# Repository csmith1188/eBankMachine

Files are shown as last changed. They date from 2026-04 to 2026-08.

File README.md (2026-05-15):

# eBanks Machine

ESP32-powered DigiPog / Pog kiosk with keypad control, NFC card support, Formbar transfers, servo-driven dispensing, deposit sensing, and a web debug / OTA page.

---

## 1. What you need

### Software

- Arduino IDE 2.x
- ESP32 board support package
- USB serial driver for your ESP32 board
- This project folder with `eBankMachine.ino` and the `.cpp/.h` files in the same sketch folder

### Arduino libraries

Install these from the Arduino Library Manager unless you already have them:

- `ArduinoJson`
- `LiquidCrystal_I2C`
- `Keypad`
- `ESP32Servo`
- `Adafruit PN532`
- `Crypto`

The ESP32 core provides these automatically:

- `WiFi`
- `WebServer`
- `ESPmDNS`
- `Update`
- `HTTPClient`
- `WiFiClientSecure`
- `Wire`

---

## 2. USB driver setup

Your computer needs the correct USB-to-serial driver before the ESP32 appears as a port.

### How to tell which driver you need

Look at the small USB chip on the ESP32 board, near the USB port.

Common chips:

| Chip on board | Driver to install |
|---|---|
| CH340 / CH341 | CH340 driver |
| CP2102 / CP210x | Silicon Labs CP210x driver | `The one I used `
| FT232 / FTDI | FTDI VCP driver |
| Native USB ESP32-S2 / S3 / C3 | Usually no extra driver needed on modern Windows/macOS/Linux |

Most cheap ESP32 DevKit boards use either **CH340** or **CP2102**.

### Windows

1. Plug in the ESP32 with a data USB cable.
2. Open **Device Manager**.
3. Check **Ports (COM & LPT)**.
4. If you see something like `USB-SERIAL CH340`, `CP210x USB to UART Bridge`, or `USB Serial Device`, the driver is working.
5. If it shows up under **Other devices** or has a warning icon, install the matching driver.
6. Unplug and replug the ESP32 after installing the driver.
7. In Arduino IDE, go to **Tools > Port** and select the new COM port.

### macOS

1. Plug in the ESP32 with a data USB cable.
2. In Arduino IDE, check **Tools > Port**.
3. Look for a port like:
   - `/dev/cu.usbserial-*`
   - `/dev/cu.SLAB_USBtoUART`
   - `/dev/cu.wchusbserial*`
4. If no port appears, install the CH340 or CP210x driver depending on the board.
5. Reboot if macOS still does not show the port.

### Linux / Chromebook Linux container

1. Plug in the ESP32.
2. Run:

```bash
ls /dev/ttyUSB* /dev/ttyACM*
```

3. Common ports are:
   - `/dev/ttyUSB0`
   - `/dev/ttyACM0`

4. If the port exists but Arduino cannot use it, add your user to the serial group:

```bash
sudo usermod -aG dialout $USER
```

5. Log out and back in.

---

## 3. USB cable warning

A lot of USB cables are charge-only. They power the ESP32 but do not carry data.

If the ESP32 lights up but no port appears:

- Try a different USB cable.
- Try a different USB port.
- Avoid USB hubs while troubleshooting.
- Use a cable that you know can transfer files, not just charge.

---

## 4. Arduino IDE board settings

In Arduino IDE:

1. Install ESP32 board support:
   - Open **Boards Manager**.
   - Search `esp32`.
   - Install **esp32 by Espressif Systems**.
2. Select a board:
   - Usually **ESP32 Dev Module** works.
3. Select the port:
   - **Tools > Port > COMx** on Windows
   - **Tools > Port > /dev/cu...** on macOS
   - **Tools > Port > /dev/ttyUSB0** or `/dev/ttyACM0` on Linux
4. Good default upload settings:
   - Upload Speed: `115200` or `921600`
   - CPU Frequency: `240MHz`
   - Flash Mode: `DIO`
   - Partition Scheme: `Default 4MB with spiffs` or normal default

If upload fails at `Connecting...`, hold the ESP32 **BOOT** button until the upload starts, then release it.

---

## 5. First upload

1. Open `eBankMachine.ino` in Arduino IDE.
2. Make sure all project files are in the same sketch folder.
3. Click **Verify**.
4. Fix any missing library errors.
5. Click **Upload**.
6. Open Serial Monitor at `115200 baud`.

After booting, the LCD should show the startup / welcome screens.

---

## 6. Finding the ESP32 on the network

The machine connects to Wi-Fi using the values in `config.cpp`.

Before uploading, set:

```cpp
const char* WIFI_SSID = "YOUR_WIFI_NAME";
const char* WIFI_PASS = "YOUR_WIFI_PASSWORD";
```

### Option A: use the keypad

Press **B three times** on the keypad. The LCD should show the ESP32 IP address if Wi-Fi is connected.

Then open:

```text
http://ESP_IP_ADDRESS/
http://ESP_IP_ADDRESS/debug
```

Example:

```text
http://192.168.1.50/debug
```

### Option B: use Serial Monitor

Open Serial Monitor at `115200 baud` and reset the ESP32.

Look for lines like:

```text
HTTP: http://192.168.x.x/
Debug: http://192.168.x.x/debug
```

### Option C: try mDNS

The project sets an OTA host name. Try:

```text
http://digipog-kiosk.local/
http://digipog-kiosk.local/debug
```

This may not work on every school network or Windows setup. The raw IP address is more reliable.

---

## 7. Web pages

### Main OTA page

```text
http://ESP_IP_ADDRESS/
```

Default login page:

```text
username: admin
password: admin
```

The OTA upload form then asks for the OTA password from `config.cpp`.

### Debug page

```text
http://ESP_IP_ADDRESS/debug
```

The debug page shows:

- current mode
- motion state
- Wi-Fi status
- inventory count
- limit switch status
- live debug log
- testing controls
- servo test buttons
- IR scan tools
- NFC scan tools
- reboot button

Warning: in the current code, `/debug` is not protected by a login. Anyone on the same network who knows the IP can open it.

---

## 8. OTA update flow

After the first USB upload, you can upload newer firmware through the browser.

1. Build/export the compiled binary from Arduino IDE.
2. Open:

```text
http://ESP_IP_ADDRESS/
```

3. Log in.
4. Choose the `.bin` file.
5. Enter the OTA password.
6. Upload.
7. The ESP32 reboots after a successful update.

If OTA fails, go back to USB upload.

---

## 9. Troubleshooting: computer cannot find ESP32

### No port appears at all

Most likely causes:

- charge-only USB cable
- missing CH340 / CP210x driver
- bad USB port
- bad board

Fix:

1. Try another USB cable.
2. Try another USB port.
3. Install the correct USB serial driver.
4. Replug the board.
5. Check Device Manager / Arduino Port menu again.

### Port appears, but upload fails

Try:

- Hold **BOOT** while uploading.
- Press **EN / RESET** once when Arduino says `Connecting...`.
- Lower upload speed to `115200`.
- Close Serial Monitor before uploading.
- Make sure no other program is using the COM port.

### Upload works, but Wi-Fi page does not load

Check:

- Wi-Fi SSID and password in `config.cpp`.
- ESP32 and computer are on the same network.
- School networks may block device-to-device traffic.
- Use the IP from the LCD or Serial Monitor instead of `.local`.

### `.local` address does not work

Use the IP address instead:

```text
http://ESP_IP_ADDRESS/debug
```

mDNS is convenient, but it is not guaranteed on every network.

### ESP32 keeps rebooting

Check:

- power supply is stable
- servo is not pulling too much current from the ESP32
- wiring shorts
- Serial Monitor crash messages
- correct board selected in Arduino IDE

---

## 10. Important security notes

This project contains Wi-Fi credentials, API keys, kiosk account info, and OTA credentials in code.

Before sharing publicly:

- remove real Wi-Fi passwords
- rotate exposed API keys
- remove real kiosk PINs
- move secrets into a separate ignored config file
- protect `/debug`
- change the default web login

Recommended repo setup:

```text
config.example.cpp   safe placeholder config
config.cpp           real private config, ignored by git
.gitignore           includes config.cpp
```

Example `.gitignore` entry:

```gitignore
config.cpp
*.bin
*.elf
*.map
```

---

## 11. Basic mode controls

From the main menu:

| Key | Mode |
|---|---|
| A | DigiPogs to Pogs / withdraw |
| B | Pogs to DigiPogs / deposit |
| C | Student-to-student transfer |
| D | NFC card write |
| B x3 | Show IP address |

Inside most flows:

| Key | Action |
|---|---|
| `#` | confirm / next |
| `*` | cancel / clear / back |

---

## 12. Current known notes

- `/debug` is powerful and currently not protected.
- First upload must be done over USB.
- OTA only works after Wi-Fi connects.
- If the ESP32 cannot be found, fix USB drivers/cable before debugging the code.
- If the network blocks local devices, the web UI may not load even though Wi-Fi connects.

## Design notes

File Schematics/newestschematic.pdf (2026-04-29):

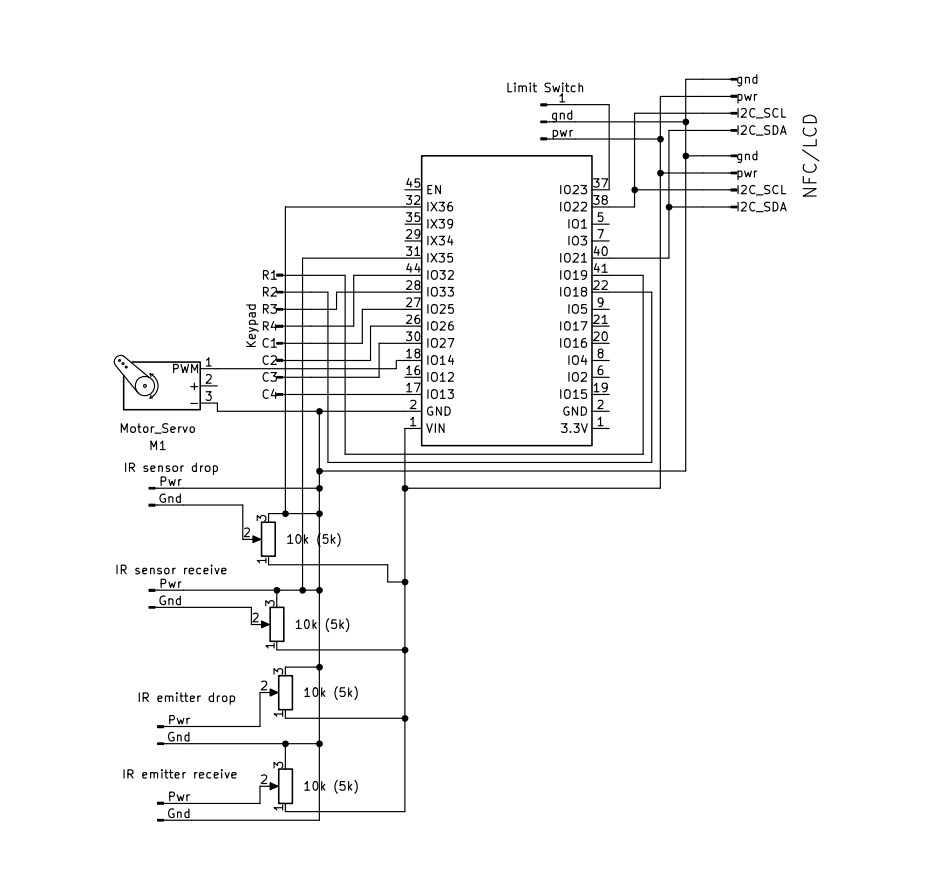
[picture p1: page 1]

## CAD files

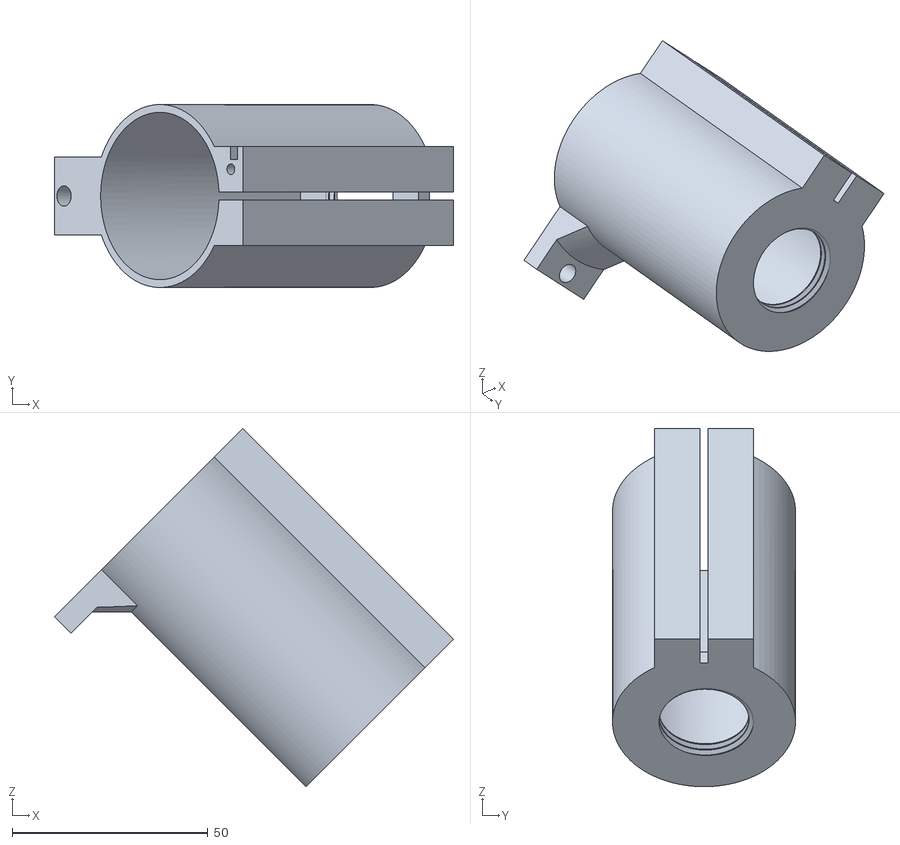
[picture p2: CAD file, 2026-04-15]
atm_stls/Dispensor_PogDispensor v14_Box_1_Body1.stl
102.0 x 46.8 x 91.6

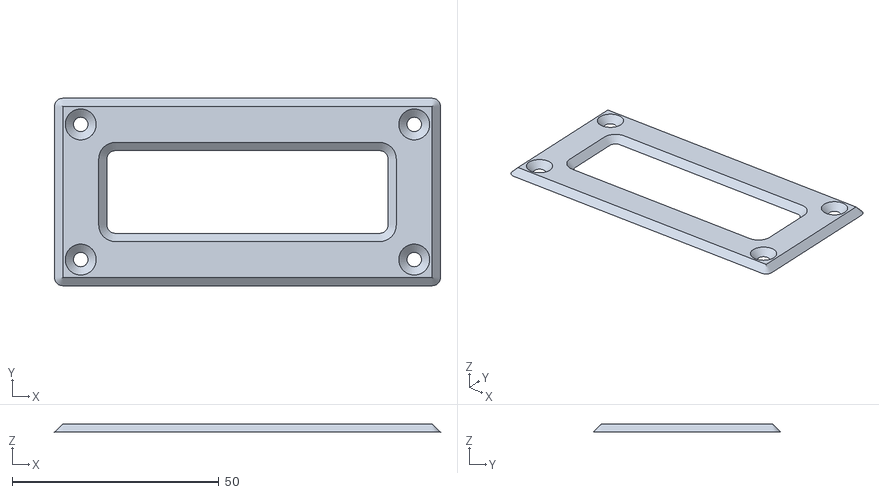
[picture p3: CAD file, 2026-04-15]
atm_stls/Panels_ATM_Panels v2_LCD_1_Body1.stl
93.4 x 45.4 x 2.00

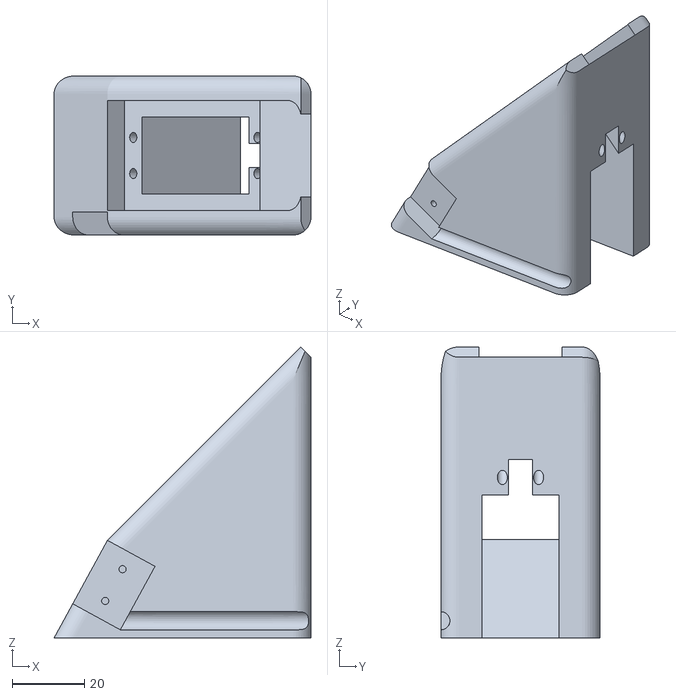
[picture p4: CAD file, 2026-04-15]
atm_stls/Dispensor_PogDispensor v14_Stand_1_Body1.stl
71.1 x 44.0 x 80.5

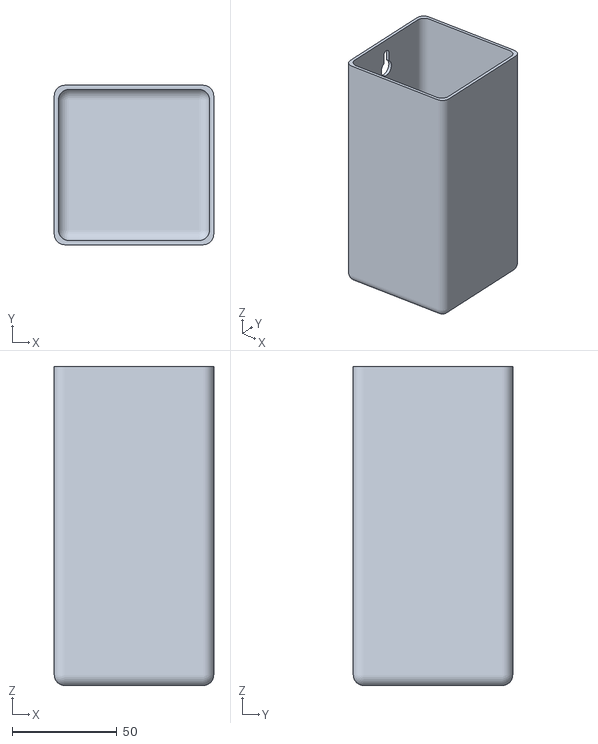
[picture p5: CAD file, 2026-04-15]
atm_stls/ReceiverBox.stl
76.2 x 76.2 x 152.4

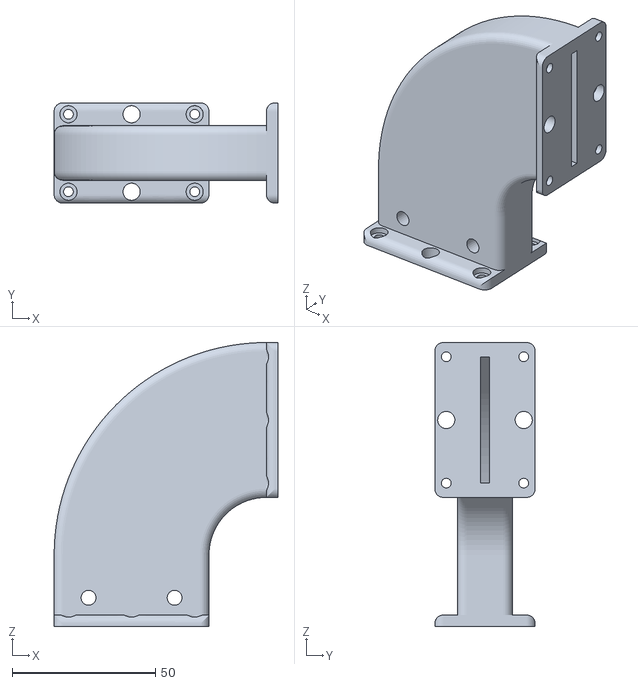
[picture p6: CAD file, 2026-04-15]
atm_stls/Receiver.stl
78.0 x 35.0 x 99.0

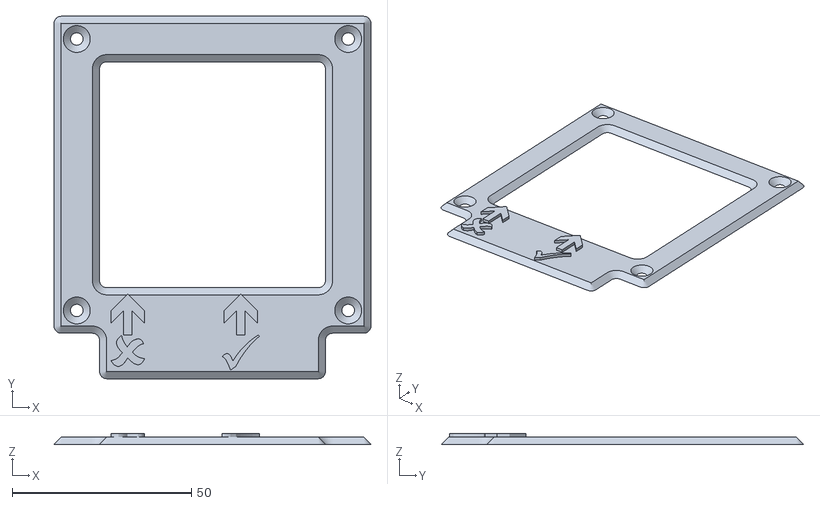
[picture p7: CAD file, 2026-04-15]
atm_stls/Panels_ATM_Panels v2_Keypad_1_Body1.stl
88.4 x 101.1 x 3.00

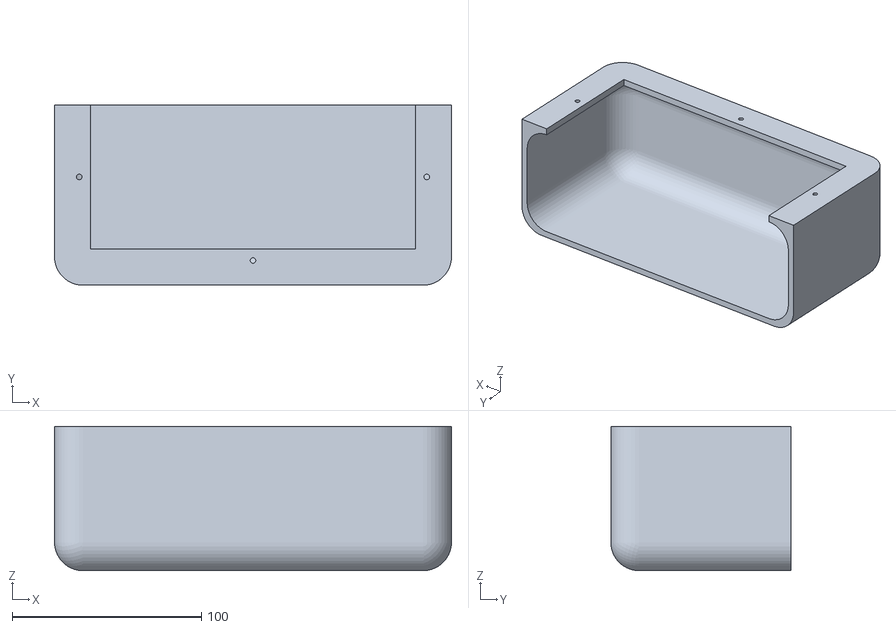
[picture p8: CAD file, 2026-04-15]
atm_stls/DropperBox.stl
209.5 x 95.2 x 76.2

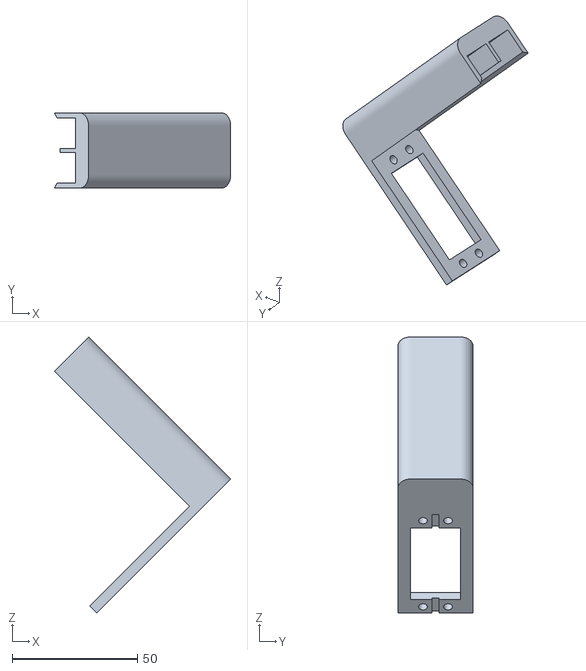
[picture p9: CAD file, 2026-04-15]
atm_stls/Dispensor_PogDispensor v14_Motor_1_Body1.stl
70.3 x 30.0 x 110.2

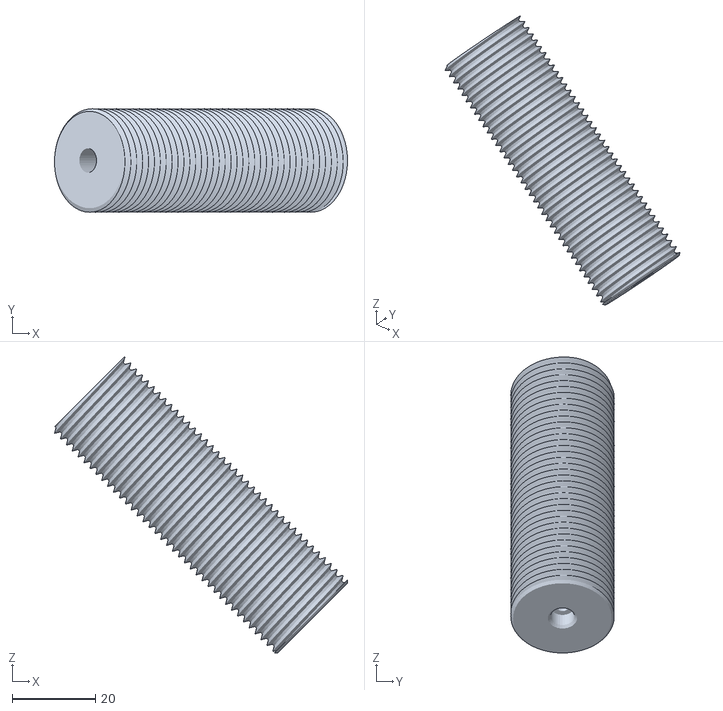
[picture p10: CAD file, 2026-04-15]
atm_stls/Dispensor_PogDispensor v14_Scroo_1_Body1.stl
70.3 x 24.8 x 71.0

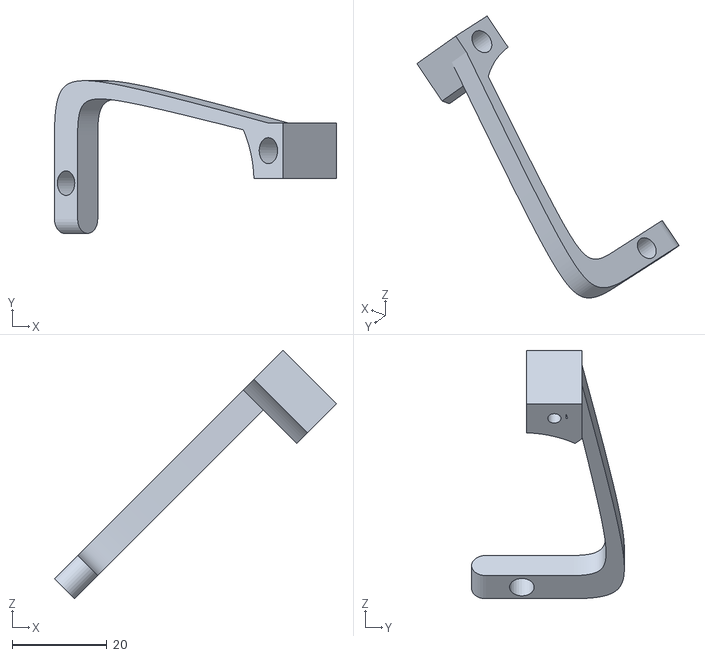
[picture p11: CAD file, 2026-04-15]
atm_stls/Dispensor_PogDispensor v14_IRArm_1_Body1.stl
59.5 x 32.2 x 52.4

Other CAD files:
atm_stls/Dropper.f3d
atm_stls/DropperBox.f3d
atm_stls/Panels.f3d
atm_stls/Receiver.f3d
atm_stls/ReceiverBox.f3d

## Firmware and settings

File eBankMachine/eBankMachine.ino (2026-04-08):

#include "eBankMachine.h"

void setup() {
  Serial.begin(115200);
  delay(200);

  dbgClear();
  dbgPrintf("BOOT\n");

  hardwareInit();

  // WiFi initial connect (15s)
  WiFi.mode(WIFI_STA);
  WiFi.setSleep(false);
  WiFi.begin(WIFI_SSID, WIFI_PASS);

  unsigned long startAttemptTime = millis();
  while (WiFi.status() != WL_CONNECTED && millis() - startAttemptTime < 15000) {
    delay(250);
  }



  if (WiFi.status() == WL_CONNECTED) {
    dbgPrintf("WiFi OK IP=%s\n", WiFi.localIP().toString().c_str());
    dbgPrintf("MAC=%s\n", WiFi.macAddress().c_str());
    setupWebOtaOnce();
  } else {
    dbgPrintf("WiFi FAILED\n");
  }

  showModeMenu();
}

void loop() {
  otaTick();

  if (WiFi.status() != WL_CONNECTED) wifiEnsureConnected();

  refundTick();
  limitSwitchTick();

  dropTick();
  depositTick();
  cardTick();

  nfcWriteTick();

  keypadTick();

  delay(1);
}

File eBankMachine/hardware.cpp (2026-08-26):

#include "eBankMachine.h"

static bool servoAttached = false;

void servoAttach() {
  if (!servoAttached) {
    myServo.setPeriodHertz(50);
    myServo.attach(SERVO_PIN, 500, 2400);
    servoAttached = true;
  }
}

void servoStopDetach() {
  if (servoAttached) {
    myServo.writeMicroseconds(neutral_us);
    delay(10);
    myServo.detach();
    servoAttached = false;
  }
}

static void calibrateIRPin(int pin, int& thrOut) {
  long sum = 0;
  otaDelay(200);
  for (int i = 0; i < CALIB_READS; i++) {
    sum += analogRead(pin);
    otaDelay(25);
  }
  int baseline = sum / CALIB_READS;
  thrOut = baseline + 300;
  if (thrOut > 3900) thrOut = 3900;
  if (thrOut < 0) thrOut = 0;
}

void IR_Calibration() {
  showMsg("IR Calibrating", "Keep chutes clear", 0);

  calibrateIRPin(IR_DROP_PIN, IR_DROP_THRESHOLD);
  calibrateIRPin(IR_DEP_PIN, IR_DEP_THRESHOLD);

  irLastSample = millis();
  irWasAbove = false;

  depLastSampleUs = micros();
  depWasAbove = false;

  dbgPrintf("IR thr drop=%d dep=%d\n", IR_DROP_THRESHOLD, IR_DEP_THRESHOLD);
}

void handleLimitPressed() {
  dbgPrintf("LIMIT pressed\n");

if (motionState == MS_DROPPING) {

  // Only allow refunds during real DIGI -> POGS withdraw mode (not debug drops)
  bool allowRefund =
      (tradeMode == MODE_DIGI_TO_REAL) &&
      !dbgDropAllAutoStop;   // extra safety: block "/debug/dropall"

  if (allowRefund) {
    int remainingPogs = (int)targetDrops - (int)droppedCount;
    if (remainingPogs < 0) remainingPogs = 0;

    int remainingDpogs = remainingPogs * DIGIPOGS_PER_POG_WITHDRAW;

    if (remainingDpogs > 0 && wzFrom > 0) {
      refundPending = true;
      refundToId = wzFrom;
      refundDigipogs = remainingDpogs;
      nextRefundTryAt = millis();
      dbgPrintf("Refund pending to=%ld dpogs=%d\n", refundToId, refundDigipogs);
    } else {
      refundPending = false;
      refundToId = 0;
      refundDigipogs = 0;
    }
  } else {
    // Debug/manual drops should never create refunds
    refundPending = false;
    refundToId = 0;
    refundDigipogs = 0;
  }

  servoStopDetach();
  motionState = MS_IDLE;
  currencyCount = MAX_CURRENCY_CAPACITY;
  targetDrops = 0;
  droppedCount = 0;
}
  showMsg("LIMIT HIT", "UNJAM UP 40s", 0);
  servoAttach();
  myServo.writeMicroseconds(SERVO_UP_US);
  otaDelay(40000);
  servoStopDetach();

  wzState = WZ_ENTER_FROM;
  numLen = 0;
  numBuf[0] = '\0';

  if (refundPending) {
    showMsg("Refunding...", "Please wait", 0);
    bool sent = trySendRefundNow();
    if (sent) showMsg("Refund SENT", "OK", 1500);
    else {
      nextRefundTryAt = millis() + REFUND_RETRY_MS;
      showMsg("Refund FAILED", "Auto retry...", 1800);
    }
  } else {
    showMsg("Recovered", "Ready", 1200);
  }

  tradeMode = MODE_SELECT;
  showModeMenu();
}

void limitSwitchTick() {
  int reading = digitalRead(SWITCH_PIN);
  if (reading != lastReading) {
    lastChange = millis();
    lastReading = reading;
  }
  if (millis() - lastChange > DEBOUNCE_MS && reading != stableState) {
    stableState = reading;
    limitSwitchPressed = (ACTIVE_LOW ? (stableState == LOW) : (stableState == HIGH));
  }
  digitalWrite(LED_PIN, limitSwitchPressed ? HIGH : LOW);

  if (limitSwitchPressed && !prevLimitSwitchPressed) {
    prevLimitSwitchPressed = true;
    handleLimitPressed();
    return;
  }
  if (!limitSwitchPressed && prevLimitSwitchPressed) {
    prevLimitSwitchPressed = false;
  }
}

void hardwareInit() {
  pinMode(LED_PIN, OUTPUT);
  digitalWrite(LED_PIN, LOW);

  pinMode(SWITCH_PIN, ACTIVE_LOW ? INPUT_PULLUP : INPUT_PULLDOWN);

  lastReading = digitalRead(SWITCH_PIN);
  stableState = lastReading;
  limitSwitchPressed = (ACTIVE_LOW ? (stableState == LOW) : (stableState == HIGH));
  prevLimitSwitchPressed = limitSwitchPressed;

  keypad.setDebounceTime(15);
  keypad.getKeys();
  delay(20);
  keypad.getKeys();
  for (int i = 0; i < LIST_MAX; i++) {
    KeyState s = keypad.key[i].kstate;
    if (s == PRESSED || s == HOLD) {
      dbgPrintf("KEYPAD held at boot: %c\n", keypad.key[i].kchar);
    }
  }

  Wire.begin(SDA_PIN, SCL_PIN);
  delay(40);

  lcd.init();
  lcd.backlight();
  showMsg("BOOTING...", nullptr, 500);

  nfc.begin();
  uint32_t v = nfc.getFirmwareVersion();
  if (v) nfc.SAMConfig();

  IR_Calibration();

  if (limitSwitchPressed) handleLimitPressed();
}

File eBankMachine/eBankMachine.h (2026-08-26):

#pragma once

#include <Arduino.h>
#include <WiFi.h>
#include <WiFiClient.h>
#include <WebServer.h>
#include <ESPmDNS.h>
#include <Update.h>

#include <WiFiClientSecure.h>
#include <HTTPClient.h>
#include <ArduinoJson.h>

#include <Wire.h>
#include <LiquidCrystal_I2C.h>
#include <Keypad.h>
#include <ESP32Servo.h>
#include <Adafruit_PN532.h>

/* ===================== CONFIG ===================== */
extern const char* WIFI_SSID;
extern const char* WIFI_PASS;

extern const char* TRANSFER_URL;
extern const char* API_KEY;

// NEW: user lookup base URL (append numeric id)
extern const char* USER_LOOKUP_BASE;

extern const int KIOSK_ID;
extern const int KIOSK_ACCOUNT_PIN;

extern const int DIGIPOGS_PER_POG_WITHDRAW;
extern const int DIGIPOGS_PER_POG_DEPOSIT;

extern const char* OTA_HOST;
extern const char* OTA_PASSWORD;

static constexpr int SDA_PIN = 21;
static constexpr int SCL_PIN = 22;

static constexpr uint8_t LCD_ADDR = 0x27;

static constexpr int PN532_IRQ = -1;
static constexpr int PN532_RESET = -1;
static constexpr uint16_t PN532_TIMEOUT_MS = 100;

static constexpr int IR_DROP_PIN = 34;
static constexpr int IR_DEP_PIN = 35;

static constexpr int SERVO_PIN = 14;

static constexpr int SWITCH_PIN = 23;
static constexpr bool ACTIVE_LOW = true;

#ifndef LED_BUILTIN
#define LED_BUILTIN 2
#endif
static constexpr int LED_PIN = LED_BUILTIN;

extern const unsigned long DEBOUNCE_MS;

extern const unsigned long IR_SAMPLE_MS;
extern const unsigned long DEP_SAMPLE_US;
extern const unsigned long DROP_COOLDOWN_MS;
extern const unsigned long DEP_COOLDOWN_MS;

extern int bPressCount;
extern unsigned long bWindowStart;

enum FbErr {
  FB_OK = 0,
  FB_NO_WIFI,     // WiFi not connected
  FB_BEGIN_FAIL,  // https.begin failed (DNS/TLS/URL)
  FB_POST_FAIL,   // https.POST returned <= 0 (timeout/connection)
  FB_HTTP_FAIL,   // server responded but not 2xx
  FB_JSON_FAIL,   // response not JSON / parse error
  FB_API_REJECT   // JSON ok but success == false (pin/balance/etc)
};

const char* fbErrMsg(FbErr e);

// new enhanced transfer
bool formbarTransferEx(int from, int to, int amount, const char* reason, int pin,
                       String& outResp, int& outHttp, FbErr& outErr);

extern const int CALIB_READS;

extern const unsigned long D_WINDOW_MS;
extern const unsigned long NFC_POLL_MS;

extern const unsigned long REFUND_RETRY_MS;

extern int neutral_us;
extern int SERVO_DOWN_US;
extern int SERVO_UP_US;

/* ===================== GLOBALS ===================== */
extern WebServer server;
extern LiquidCrystal_I2C lcd;
extern Servo myServo;
extern Adafruit_PN532 nfc;
extern Keypad keypad;

extern bool otaStarted;

/* Debug buffer */
void dbgClear();
void dbgAppend(const char* s);
void dbgPrintf(const char* fmt, ...);

/* Modes */
enum TradeMode {
  MODE_SELECT,
  MODE_DIGI_TO_REAL,
  MODE_REAL_TO_DIGI,
  MODE_UPDATE_CARD,
  MODE_STU_TO_STU,
  MODE_NFC_WRITE     // NEW
};
extern TradeMode tradeMode;

extern char numBuf[10];
extern uint8_t numLen;

/* Withdraw wizard */
enum WizardState {
  WZ_ENTER_FROM,
  WZ_CONFIRM_FROM,  // NEW
  WZ_ENTER_PIN,
  WZ_ENTER_POGS,
  WZ_CONFIRM
};
extern WizardState wzState;
extern long wzFrom, wzPin, wzPogs;

/* Deposit */
enum DepositState {
  DEP_ENTER_ID,
  DEP_CONFIRM_ID,  // NEW
  DEP_SCANNING
};

/* Student->Student transfer wizard */
enum StuWizardState {
  ST_ENTER_FROM,
  ST_CONFIRM_FROM,
  ST_ENTER_PIN,
  ST_ENTER_TO,
  ST_CONFIRM_TO,
  ST_ENTER_AMOUNT,
  ST_CONFIRM_SEND
};

extern StuWizardState stState;
extern long stFrom, stPin, stTo, stAmt;

void startStudentTransferFlow();
void handleStudentTransferKey(char k);

/* NFC write */
enum NfcWriteState {
  NFCW_ENTER_ID,
  NFCW_WAIT_HOLD,     // waiting for tag + stable hold
  NFCW_WRITING,       // performing write
  NFCW_VERIFY,        // readback verify
  NFCW_WAIT_REMOVE    // wait until tag removed
};

extern NfcWriteState nfcwState;
extern long nfcwId;

extern unsigned long nfcwHoldStartMs;
extern bool nfcwHoldActive;

void startNfcWriteFlow();
void handleNfcWriteKey(char k);
void nfcWriteTick();

/* writes "ID:xxxxx" as NDEF Text record */
bool ntagWriteIdText(long id);

bool ntagWriteFullCard(const String& website, const String& name, long formbarId, long formbarPin);

/* reads first NTAG user pages and looks for ASCII "ID:####"; returns true if found */
bool ntagTryReadIdText(long& outId);

extern DepositState depState;
extern long depToId;
extern int depositCount;

/* Inventory */
extern int currencyCount;
extern const int MAX_CURRENCY_CAPACITY;
extern const int LOW_STOCK_THRESHOLD;

// Debug: drop timing
extern bool dbgDropTimingEnabled;
extern bool dbgDropAllAutoStop;
extern unsigned long dbgDropLastEventMs;
extern unsigned long dbgDropSumIntervalsMs;
extern unsigned long dbgDropIntervals;

/* temp display buffer for user name during ID confirmation */
extern char idNameBuf[17];

/* Limit switch debounce */
extern int lastReading;
extern int stableState;
extern unsigned long lastChange;
extern bool limitSwitchPressed;
extern bool prevLimitSwitchPressed;

/* IR thresholds/state */
extern int IR_DROP_THRESHOLD;
extern int IR_DEP_THRESHOLD;

extern unsigned long irLastSample;
extern unsigned long nextCountAllowedAt;
extern bool irWasAbove;
extern unsigned long dropStartMs;

void showNfcWriteEnterId();
void showNfcWriteTap();

extern bool depWasAbove;
extern unsigned long depNextAllowedAt;
extern unsigned long depStartMs;
extern unsigned long depLastSampleUs;

/* Drop counters */
extern volatile int targetDrops;
extern volatile int droppedCount;

enum MotionState { MS_IDLE,
                   MS_DROPPING };
extern MotionState motionState;

/* Refund */
extern bool refundPending;
extern long refundToId;
extern int refundDigipogs;
extern unsigned long nextRefundTryAt;

/* Debug keypad shortcuts */
extern int dPressCount;
extern unsigned long dWindowStart;
extern int cPressCount;
extern unsigned long cWindowStart;

/* ===================== PROTOTYPES ===================== */
/* ui */
void otaDelay(unsigned long ms);
void showMsg(const char* line0, const char* line1 = nullptr, unsigned long ms = 0);
void showModeMenu();
void clearEntryLine();
void showEntry(const __FlashStringHelper* prompt);
void showConfirmWithdraw(long pogs);
void showDepositEnterId();
void showDepositScanning();

// NEW: confirm screen used for ID confirmation
void showConfirmId(const char* line1, long id, const char* name);

/* ota web */
void setupWebOtaOnce();
void otaTick();

/* net */
void wifiEnsureConnected();

/* formbar */
bool formbarTransfer(int from, int to, int amount, const char* reason, int pin, String& outResp, int& outHttp);
bool trySendRefundNow();

// NEW: ID existence check (GET /api/user/{id})
bool formbarUserExists(int id, String& outName, int& outHttp);

extern unsigned long depBeamStartMs;
extern bool depBeamTiming;
extern unsigned long depLastBeamMs;
extern unsigned long depMaxBeamMs;
extern const unsigned long DEP_BEAM_MIN_MS;
extern const unsigned long DEP_BEAM_MAX_MS;
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

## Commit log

2026-02-26 Prevented SoftLocks
    Added cancels to prevent getting soft locked into a menu
    [withdraw.cpp]
2026-02-26 Fixed Wrapper
    Wrapper now uses I2C if defined in the eBankMachine.h in the LCD Wrapper Class and uses serial if I2C isn't defined
    [LCDWrapper.cpp, eBankMachine.h, hardware.cpp]
2026-02-26 Fixes
    made more fixes to the wrapper
    [LCDWrapper.cpp, eBankMachine.h]
2026-02-27 for matt
    [partitions.csv]
2026-04-15 Added STLs
    [Dispensor_PogDispensor v14_Box_1_Body1.stl, Dispensor_PogDispensor v14_IRArm_1_Body1.stl, Dispensor_PogDispensor v14_Motor_1_Body1.stl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]
2026-05-15 Add README for eBanks Machine project
    Added comprehensive README documentation for eBanks Machine project, including setup instructions, USB driver information, Arduino IDE settings, troubleshooting tips, and security notes.
2026-09-18 schematic updates
    [eBankMachine.kicad_sch]
